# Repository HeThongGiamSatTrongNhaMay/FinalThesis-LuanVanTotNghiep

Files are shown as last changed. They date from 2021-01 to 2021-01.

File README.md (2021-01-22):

Monitoring System in Factory Using LoRaWAN Technology - Hệ Thống Giám Sát Thiết Bị Trong Nhà Máy
==============================
This repository contains a proof-of-concept implementation of a Monitoring 
System in Factory using LoRaWAN technology. It includes a single channel 
LoRaWAN gateway(from ESP8266, and SX1278 tranceiver) and 4 LoRaWAN node
(from ATmega328P and DHT11, DHT22 sensor, PZEM004T).

The code is for testing and development purposes only, and is not meant 
for production usage. 

Engine for gateway is based on code base of Single Channel gateway for RaspberryPI
which is developed by Thomas Telkamp. Code was ported and extended to run
on ESP 8266 mcu and provide RTC, Webserver and DNS services.

Topology for this project : 4 nodes (2 measure humidity and temperature; 2 measure ac energy).
A LoRaWAN gateway pushes data from these 4 nodes to network server TTN. Data then is forwarded 
to IoT Cloud ThingSpeak. Source code, lib and hardware are saved in this repository.

Maintained by Minh Chau (huynhminhchau.k14@gmail.com)

Features
--------
- listen on configurable frequency and spreading factor
- SF7 to SF12
- status updates
- can forward to one server
- DNS support for server lookup
- NTP Support for time sync with internet time servers
- Webserver support (default port 8080)
- ABP Activate
- frequence 433 MHz : 410 - 525 MHz

Not (yet) supported:
- PACKET_PUSH_ACK processing
- SF7BW250 modulation
- FSK modulation
- downstream messages (tx)

Dependencies
------------

- [gBase64][1] library by Adam Rudd is now integrated in the project, no need to install
- [Time][2] library Arduino [documentation][3]
- [lmic lib][4]

Connections
-----------
In Altium Designer of this repository

Configuration
-------------

Defaults: gateway, node

- LoRa:   SF7 at 486.3 Mhz
- Server: router.cn.thethings.network, port 1700  (The Things Network: router.cn.thethings.network)

Edit .h file (ESP-sc-gway.h) to change configuration (look for: "Configure these values!").

Please set location, email and description.

License
-------
The source files in this repository are made available under the Arduino IDE
v1.8.13, except for the base64 implementation, that has been
copied from the Semtech Packet Forwader.

[1]: https://github.com/adamvr/arduino-base64
[2]: https://github.com/PaulStoffregen/Time
[3]: http://playground.arduino.cc/code/time
[4]: https://github.com/HeThongGiamSatTrongNhaMay/LuanVanTotNghiep/tree/main/lib

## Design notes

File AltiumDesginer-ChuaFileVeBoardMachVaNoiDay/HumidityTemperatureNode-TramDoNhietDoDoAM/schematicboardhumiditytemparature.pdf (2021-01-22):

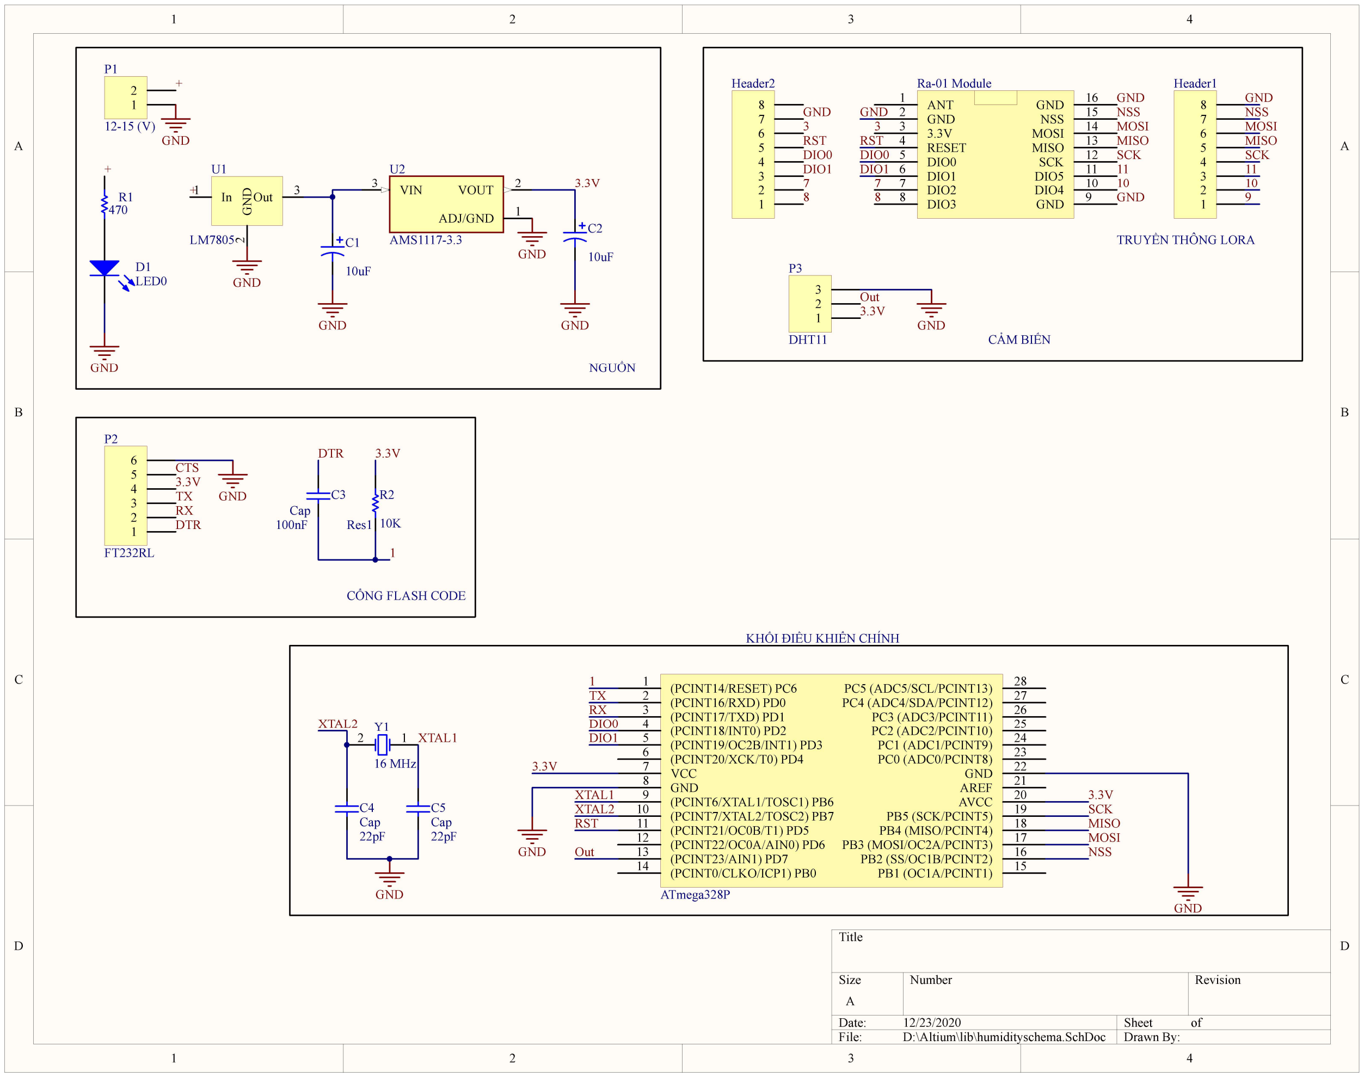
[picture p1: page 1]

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
Title

Size | Number | | Revision
A
Date: | 12/23/2020 | Sheet | of
File: | D:\Altium\lib\humidityschema.SchDoc | Drawn By:

DIO3 8

DIO2 7

DIO1 6

DIO0 5

RESET 4

3.3V 3

GND 2

ANT 1

GND | 9
DIO4 | 10 DIO5 | 11 SCK | 12 MISO | 13 MOSI | 14 NSS | 15 GND | 16

Ra-01 Module

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
Header1

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
Header2

GND
3
RST
DIO0
DIO1
7
8

GND
NSS
MOSI
MISO
SCK
11
10
9

GND
NSS
MOSI
MISO
SCK
11
10
GND

GND
3
RST
DIO0
DIO1
7
8

1

2

P1

12-15 (V)

D1
LED0

470

R1 | Out | 3 GND

2

In 1

U1

LM7805

+

+
VIN 3 | VOUT | 2
| ADJ/GND | 1

U2

AMS1117-3.3

+

10uF

C2

10uF

C1

GND

GND

GND

GND

GND

GND

3.3V

1

2

3

4

5

6

P2

FT232RL

CTS
3.3V
TX
RX
DTR

1

2

3

P3

DHT11

3.3V

Out

GND

GND

10K

R2

100nF Res1

C3
Cap

DTR 3.3V

1

(PCINT14/RESET) PC6 1
(PCINT16/RXD) PD0 2
(PCINT17/TXD) PD1 3
(PCINT18/INT0) PD2 4
(PCINT19/OC2B/INT1) PD3 5
(PCINT20/XCK/T0) PD4 6
VCC 7
GND 8
(PCINT6/XTAL1/TOSC1) PB6 9 (PCINT7/XTAL2/TOSC2) PB7 10 (PCINT21/OC0B/T1) PD5 11
(PCINT22/OC0A/AIN0) PD6 12 (PCINT23/AIN1) PD7 13
(PCINT0/CLKO/ICP1) PB0 14 | PB1 (OC1A/PCINT1) | 15 PB2 (SS/OC1B/PCINT2) | 16 PB3 (MOSI/OC2A/PCINT3) | 17 PB4 (MISO/PCINT4) | 18 PB5 (SCK/PCINT5) | 19 AVCC | 20 AREF | 21 GND | 22 PC0 (ADC0/PCINT8) | 23 PC1 (ADC1/PCINT9) | 24 PC2 (ADC2/PCINT10) | 25 PC3 (ADC3/PCINT11) | 26 PC4 (ADC4/SDA/PCINT12) | 27 PC5 (ADC5/SCL/PCINT13) | 28

ATmega328P

NGUỒN

TRUYỀN THÔNG LORA

CẢM BIẾN

CỔNG FLASH CODE

GND

GND

3.3V

3.3V

1

2 1

Y1

### 16 MHz

22pF

C5
Cap
22pF

C4
Cap

GND

XTAL1

XTAL2

TX
RX

XTAL1
XTAL2

DIO0
DIO1

RST

Out

SCK
MISO
MOSI
NSS

KHỐI ĐIỀU KHIỂN CHÍNH

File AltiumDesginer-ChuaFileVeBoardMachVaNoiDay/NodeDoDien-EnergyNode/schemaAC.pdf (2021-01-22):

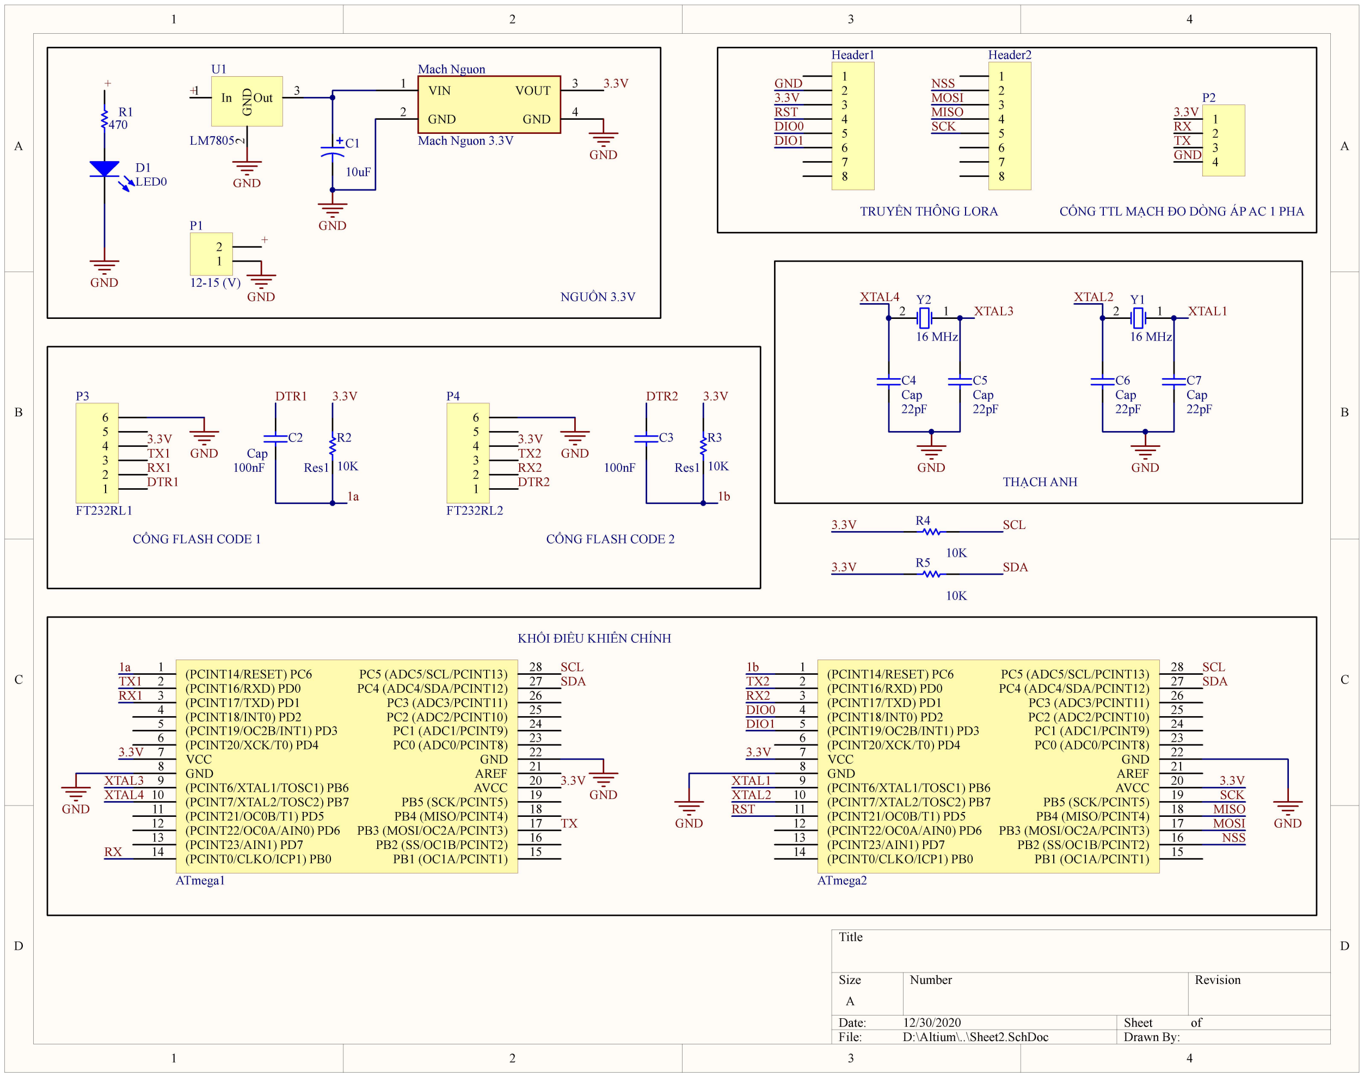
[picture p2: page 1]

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
Title

Size | Number | | Revision
A
Date: | 12/30/2020 | Sheet | of
File: | D:\Altium\..\Sheet2.SchDoc | Drawn By:

1

2

P1

12-15 (V)

D1
LED0

470

R1

Out 3 GND

2

In 1

U1

LM7805

+
+

10uF

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
FT232RL1

3.3V
TX1
RX1
DTR1

GND
10K

R2

100nF Res1

C2
Cap

DTR1 3.3V

1a

(PCINT14/RESET) PC6 1
(PCINT16/RXD) PD0 2
(PCINT17/TXD) PD1 3
(PCINT18/INT0) PD2 4
(PCINT19/OC2B/INT1) PD3 5
(PCINT20/XCK/T0) PD4 6
VCC 7
GND 8
(PCINT6/XTAL1/TOSC1) PB6 9 (PCINT7/XTAL2/TOSC2) PB7 10 (PCINT21/OC0B/T1) PD5 11
(PCINT22/OC0A/AIN0) PD6 12 (PCINT23/AIN1) PD7 13
(PCINT0/CLKO/ICP1) PB0 14 | PB1 (OC1A/PCINT1) | 15 PB2 (SS/OC1B/PCINT2) | 16 PB3 (MOSI/OC2A/PCINT3) | 17 PB4 (MISO/PCINT4) | 18 PB5 (SCK/PCINT5) | 19 AVCC | 20 AREF | 21 GND | 22 PC0 (ADC0/PCINT8) | 23 PC1 (ADC1/PCINT9) | 24 PC2 (ADC2/PCINT10) | 25 PC3 (ADC3/PCINT11) | 26 PC4 (ADC4/SDA/PCINT12) | 27 PC5 (ADC5/SCL/PCINT13) | 28

ATmega2

NGUỒN 3.3V

TRUYỀN THÔNG LORA | CỔNG TTL MẠCH ĐO DÒNG ÁP AC 1 PHA

CỔNG FLASH CODE 1

GND | GND

3.3V

3.3V

1b

2 1

Y1

### 16 MHz

22pF

C7
Cap
22pF

C6
Cap

GND

XTAL1

XTAL2

TX2
RX2

XTAL1
XTAL2

DIO0
DIO1

RST

SCK
MISO
MOSI
NSS

KHỐI ĐIỀU KHIỂN CHÍNH

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
Header2
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
Header1

GND

RST
DIO0
DIO1

NSS
MOSI
MISO
SCK

+

3.3V VIN 1

GND 2

VOUT | 3
GND | 4

Mach Nguon

Mach Nguon 3.3V
GND

3.3V

1
2
3
4

P2

2 1

Y2

### 16 MHz

22pF

C5
Cap
22pF

C4
Cap

GND

XTAL3

XTAL4

(PCINT14/RESET) PC6 1
(PCINT16/RXD) PD0 2
(PCINT17/TXD) PD1 3
(PCINT18/INT0) PD2 4
(PCINT19/OC2B/INT1) PD3 5
(PCINT20/XCK/T0) PD4 6
VCC 7
GND 8
(PCINT6/XTAL1/TOSC1) PB6 9 (PCINT7/XTAL2/TOSC2) PB7 10 (PCINT21/OC0B/T1) PD5 11
(PCINT22/OC0A/AIN0) PD6 12 (PCINT23/AIN1) PD7 13
(PCINT0/CLKO/ICP1) PB0 14 | PB1 (OC1A/PCINT1) | 15 PB2 (SS/OC1B/PCINT2) | 16 PB3 (MOSI/OC2A/PCINT3) | 17 PB4 (MISO/PCINT4) | 18 PB5 (SCK/PCINT5) | 19 AVCC | 20 AREF | 21 GND | 22 PC0 (ADC0/PCINT8) | 23 PC1 (ADC1/PCINT9) | 24 PC2 (ADC2/PCINT10) | 25 PC3 (ADC3/PCINT11) | 26 PC4 (ADC4/SDA/PCINT12) | 27 PC5 (ADC5/SCL/PCINT13) | 28

ATmega1

1

2

3

4

5

6

P4

FT232RL2

3.3V
TX2
RX2
DTR2

GND
10K

R3

100nF Res1

C3

DTR2 3.3V

1b

CỔNG FLASH CODE 2

SCL
SDA

SCL
SDA

3.3V
GND

3.3V

GND

1a
TX1
RX1

XTAL3
XTAL4

3.3V
RX
TX
GND

TX

RX

THẠCH ANH

10K

R4 3.3V | SCL

10K

R5 3.3V | SDA

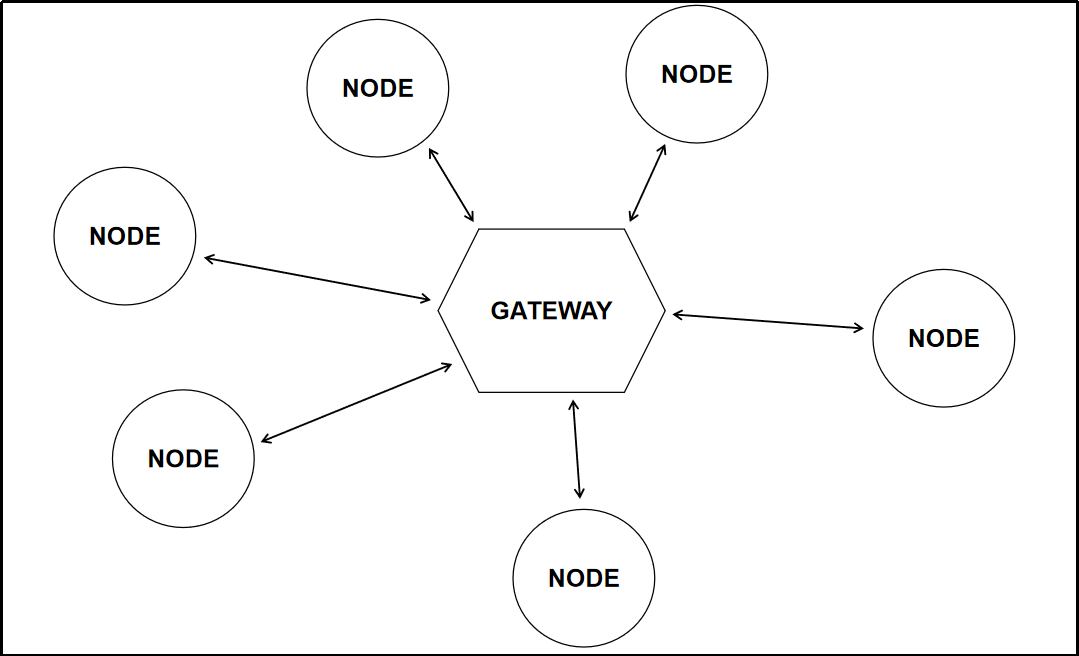
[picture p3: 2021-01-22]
topology.png

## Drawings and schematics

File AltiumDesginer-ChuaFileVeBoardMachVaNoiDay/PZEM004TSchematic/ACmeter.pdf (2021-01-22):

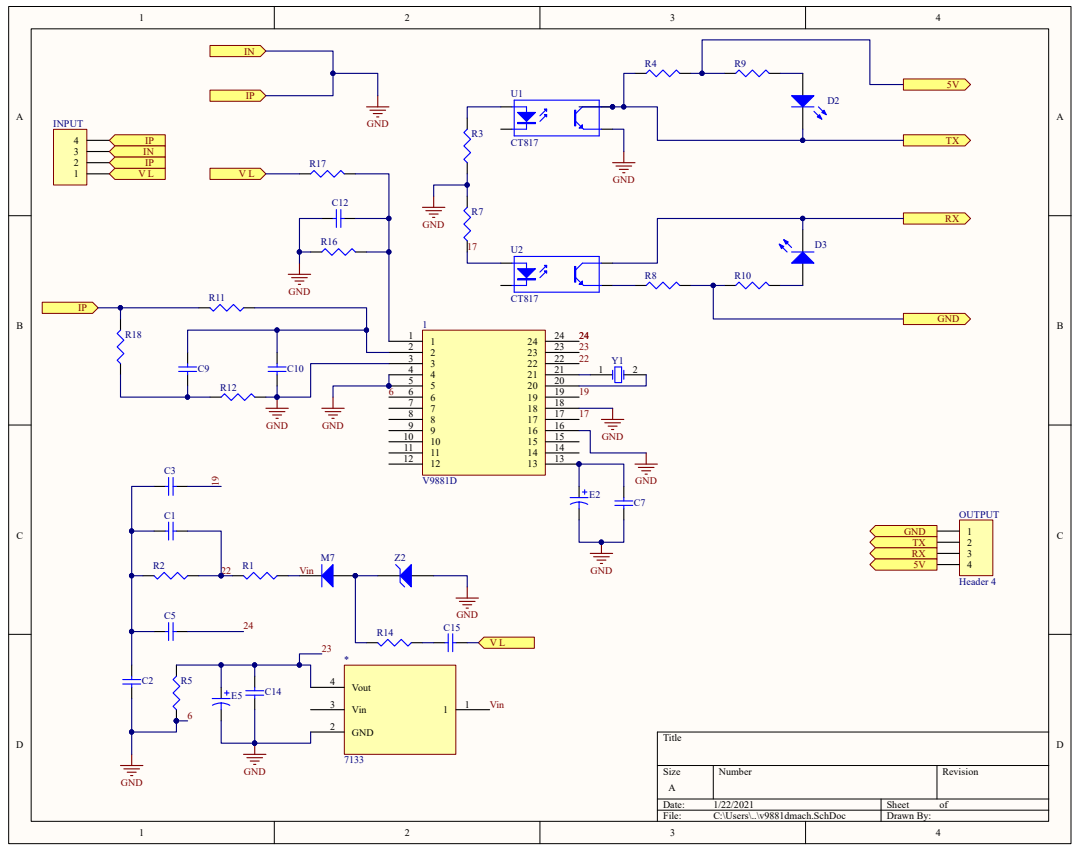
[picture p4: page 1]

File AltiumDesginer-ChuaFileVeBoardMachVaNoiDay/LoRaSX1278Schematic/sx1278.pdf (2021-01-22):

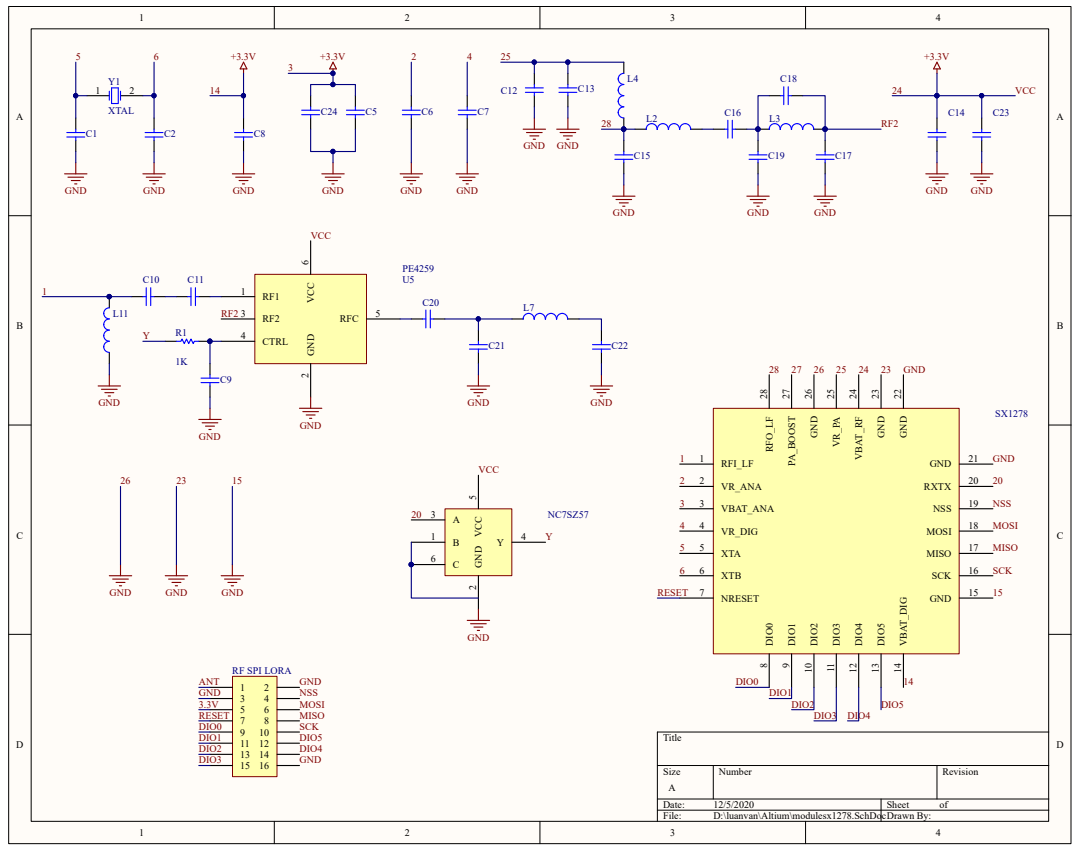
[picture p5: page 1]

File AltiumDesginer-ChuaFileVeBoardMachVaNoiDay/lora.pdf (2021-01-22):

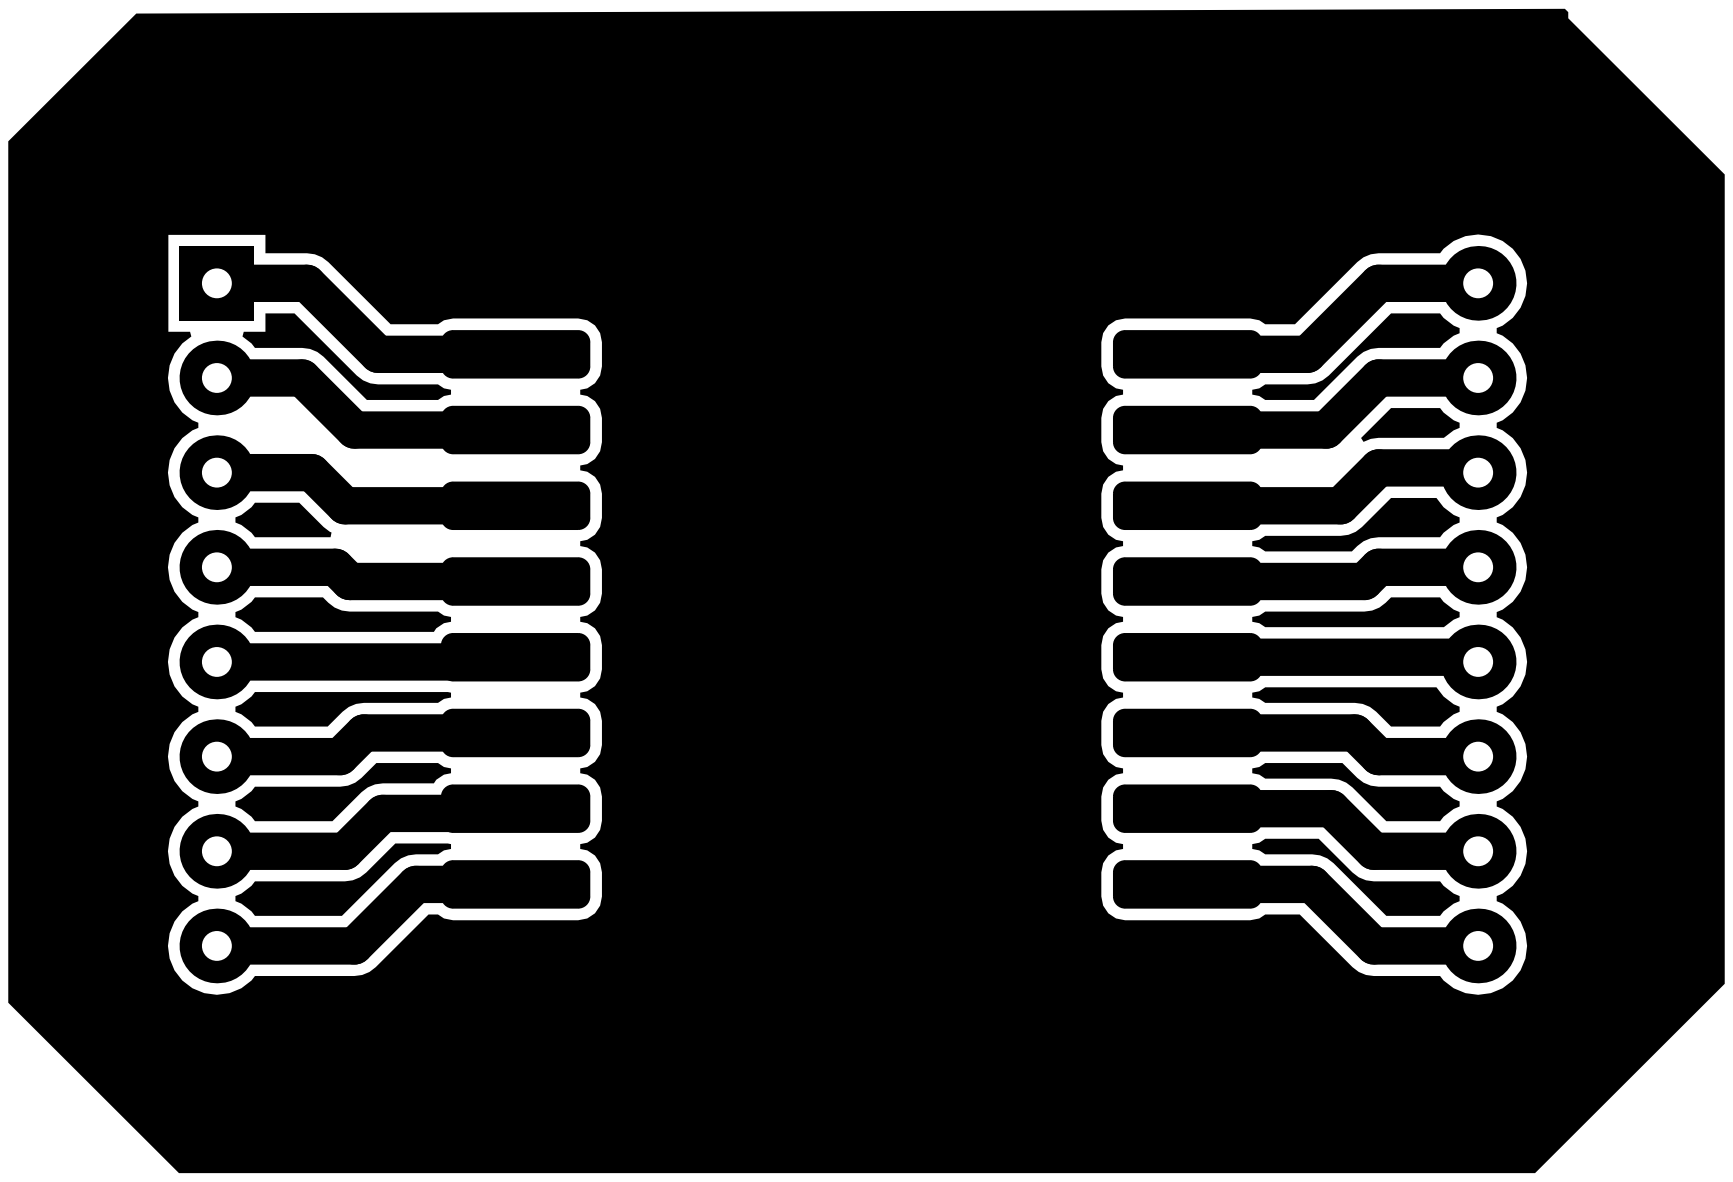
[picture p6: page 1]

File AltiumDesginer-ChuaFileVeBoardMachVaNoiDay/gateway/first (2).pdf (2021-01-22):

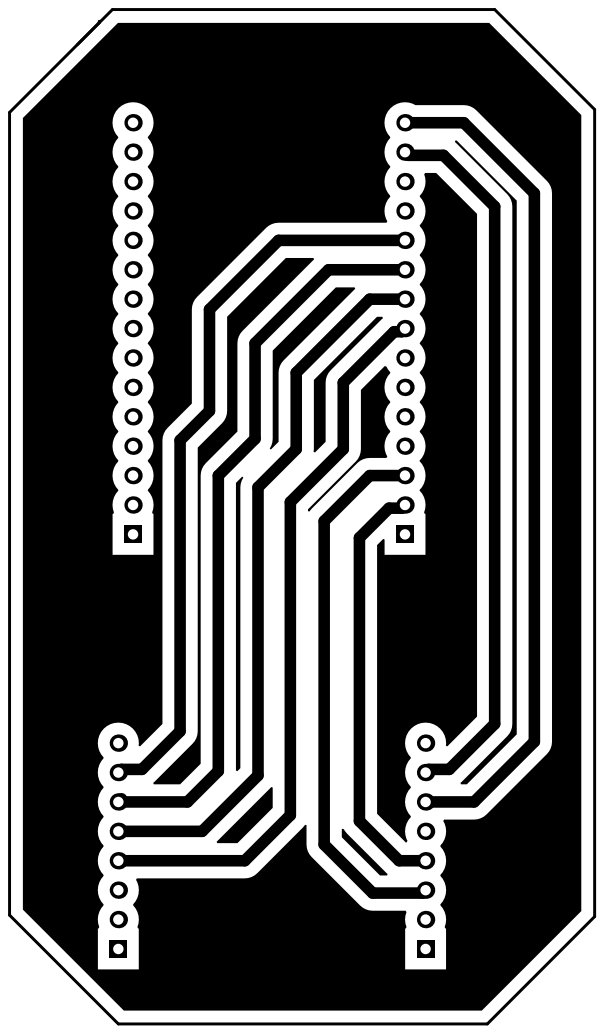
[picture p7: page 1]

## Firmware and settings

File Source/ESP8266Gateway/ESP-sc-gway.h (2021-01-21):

//
// Author: Maarten Westenberg
// Version: 1.0.0
// Date: 2016-03-25
//
// This file contains a number of compile-time settings that can be set on (=1) or off (=0)
// The disadvantage of compile time is minor compared to the memory gain of not having
// too much code compiled and loaded on your ESP8266.
//
// See http://pubsubclient.knolleary.net/api.html for API description of MQTT
//
//
// 2016-06-12 - Charles-Henri Hallard (http://hallard.me and http://github.com/hallard)
//              added support for WeMos Lora Gateway
//              added AP mode (for OTA)
//              added Over The Air (OTA) feature
//              added support for onboard WS2812 RGB Led
//              refactored include source file
//              see https://github.com/hallard/WeMos-Lora
//
// ----------------------------------------------------------------------------------------

#include <Arduino.h>

#define VERSION " ! V. 1.1.3, 110616"

// Enable WeMos Lora Shield Gateway
// see https://github.com/hallard/WeMos-Lora
// Uncomment this line if you're using this shield as gateway


/*******************************************************************************

   Configure these values if necessary!

 *******************************************************************************/

// WiFi definitions
// Setup your Wifi SSID and password
// If your device already connected to your Wifi, then
// let as is (stars), it will connect using
// your previous saved SDK credentials

//#define STASSID    "Pelab_2.4G"
//#define STAPSK    "Pelab12345678910"

//#define STASSID    "Ngoc Hien 1"
//#define STAPSK    "aaaabbbb"

#define STASSID    "iPhone"
#define STAPSK    "123456789"

// MQTT definitions
#define _TTN_SERVER "router.cn.thethings.network"


// TTN related
#define SERVER1 _TTN_SERVER    // The Things Network: croft.thethings.girovito.nl "54.72.145.119"
#define _TTN_PORT 1700            // The port on which to send data


// Gateway Ident definitions
#define _DESCRIPTION "ESP Gateway"

// SX1276 - ESP8266 connections
#define DEFAULT_PIN_SS    15          // GPIO15, D8
#define DEFAULT_PIN_DIO0  5           // GPIO5,  D1
#define DEFAULT_PIN_RST   NOT_A_PIN   // Unused


#define STATISTICS 1    // Gather statistics on sensor and Wifi status
#define DEBUG 1         // Initial value of debug var. Can be changed using the admin webserver
// For operational use, set initial DEBUG vaulue 0


#define A_MAXBUFSIZE 192  // Must be larger than 128, but small enough to work
#define _BAUDRATE 115200  // Works for debug messages to serial momitor (if attached).

// ntp
#define NTP_TIMESERVER "ch.pool.ntp.org"  // Country and region specific
#define NTP_INTERVAL  3600  // How often doe we want time NTP synchronization
#define NTP_TIMEZONES 7     // How far is our Timezone from UTC (excl daylight saving/summer time)

// ============================================================================
// Set all definitions for Gateway
// ============================================================================

#define REG_FIFO                    0x00
#define REG_FIFO_ADDR_PTR           0x0D
#define REG_FIFO_TX_BASE_AD         0x0E
#define REG_FIFO_RX_BASE_AD         0x0F
#define REG_RX_NB_BYTES             0x13
#define REG_OPMODE                  0x01
#define REG_FIFO_RX_CURRENT_ADDR    0x10
#define REG_IRQ_FLAGS               0x12
#define REG_DIO_MAPPING_1           0x40
#define REG_DIO_MAPPING_2           0x41
#define REG_MODEM_CONFIG            0x1D
#define REG_MODEM_CONFIG2           0x1E
#define REG_MODEM_CONFIG3           0x26
#define REG_SYMB_TIMEOUT_LSB        0x1F
#define REG_PKT_SNR_VALUE           0x19
#define REG_PAYLOAD_LENGTH          0x22
#define REG_IRQ_FLAGS_MASK          0x11
#define REG_MAX_PAYLOAD_LENGTH      0x23
#define REG_HOP_PERIOD              0x24
#define REG_SYNC_WORD               0x39
#define REG_VERSION                 0x42

#define SX72_MODE_RX_CONTINUOS      0x85
#define SX72_MODE_TX                0x83
#define SX72_MODE_SLEEP             0x80
#define SX72_MODE_STANDBY           0x81

#define PAYLOAD_LENGTH              0x40

// LOW NOISE AMPLIFIER
#define REG_LNA                     0x0C
#define LNA_MAX_GAIN                0x23
#define LNA_OFF_GAIN                0x00
#define LNA_LOW_GAIN                0x20

// CONF REG
#define REG1                        0x0A
#define REG2                        0x84

#define SX72_MC2_FSK                0x00
#define SX72_MC2_SF7                0x70
#define SX72_MC2_SF8                0x80
#define SX72_MC2_SF9                0x90
#define SX72_MC2_SF10               0xA0
#define SX72_MC2_SF11               0xB0
#define SX72_MC2_SF12               0xC0

#define SX72_MC1_LOW_DATA_RATE_OPTIMIZE  0x01   // mandated for SF11 and SF12

// FRF
#define REG_FRF_MSB       0x06
#define REG_FRF_MID       0x07
#define REG_FRF_LSB       0x08


#define FRF_MSB           0xD9    // 868.1 Mhz
#define FRF_MID           0x06
#define FRF_LSB           0x66
#define BUFLEN 2048               //Max length of buffer

#define PROTOCOL_VERSION  1
#define PKT_PUSH_DATA     0
#define PKT_PUSH_ACK      1
#define PKT_PULL_DATA     2
#define PKT_PULL_RESP     3
#define PKT_PULL_ACK      4

#define TX_BUFF_SIZE  2048
#define STATUS_SIZE   512           // This should(!) be enough based on the static text part.. was 1024

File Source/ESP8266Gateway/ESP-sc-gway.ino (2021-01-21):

#include <sys/time.h>
#include <SPI.h>
#include <ESP8266WiFi.h>
#include <TimeLib.h>	// https://github.com/PaulStoffregen/Time)
#include <WiFiUdp.h> 

extern "C" {
#include "user_interface.h"
#include "lwip/err.h"
#include "lwip/dns.h"
}

#include "gBase64.h"			// https://github.com/adamvr/arduino-base64 (I changed the name)
#include "ESP-sc-gway.h"	// This file contains configuration of GWay

int debug = 1;									// Debug level! 0 is no msgs, 1 normal, 2 is extensive

using namespace std;

char message[256];
char b64[256];
bool sx1272 = true;								// Actually we use sx1276/RFM95
byte receivedbytes;

uint32_t cp_nb_rx_rcv;
uint32_t cp_nb_rx_ok;
uint32_t cp_nb_rx_bad;
uint32_t cp_nb_rx_nocrc;
uint32_t cp_up_pkt_fwd;

enum sf_t { SF7 = 7, SF8, SF9, SF10, SF11, SF12 };

uint8_t MAC_array[6];
char MAC_char[18] = {0};


/*******************************************************************************

   Configure these values if necessary!

 *******************************************************************************/

// SX1276 - ESP8266 connections
int ssPin = DEFAULT_PIN_SS;
int dio0  = DEFAULT_PIN_DIO0;
int RST   = DEFAULT_PIN_RST;

// Set spreading factor (SF7 - SF12)
sf_t sf = SF7;

// Set center frequency. If in doubt, choose the first one, comment all others
// Each "real" gateway should support the first 3 frequencies according to LoRa spec.
uint32_t  freq = 486300000; 					// Channel 0, 486.3 MHz
//uint32_t  freq = 486500000; 					// Channel 1, 486.5 MHz
//uint32_t  freq = 486700000; 					// in Mhz! (486.7)
//uint32_t  freq = 486900000; 					// in Mhz! (486.9)
//uint32_t  freq = 487100000; 					// in Mhz! (487.1)
//uint32_t  freq = 487300000; 					// in Mhz! (487.3)
//uint32_t  freq = 487500000; 					// in Mhz! (487.5)
//uint32_t  freq = 487700000; 					// in Mhz! (487.7)

IPAddress ttnServer;							// IP Address of thethingsnetwork server

WiFiUDP Udp;
uint32_t lasttime;


// ----------------------------------------------------------------------------
// DIE is not use actively in the source code anymore.
// It is replaced by a Serial.print command so we know that we have a problem
// somewhere.
// There are at least 3 other ways to restart the ESP. Pick one if you want.
// ----------------------------------------------------------------------------
void die(const char *s)
{
  Serial.println(s);
  delay(50);
  // system_restart();						// SDK function
  // ESP.reset();
  abort();									// Within a second
}


// ----------------------------------------------------------------------------
// Convert a float to string for printing
// f is value to convert
// p is precision in decimal digits
// val is character array for results
// ----------------------------------------------------------------------------
void ftoa(float f, char *val, int p) {
  int j = 1;
  int ival, fval;
  char b[6];

  for (int i = 0; i < p; i++) {
    j = j * 10;
  }

  ival = (int) f;								// Make integer part
  fval = (int) ((f - ival) * j);					// Make fraction. Has same sign as integer part
  if (fval < 0) fval = -fval;					// So if it is negative make fraction positive again.
  // sprintf does NOT fit in memory
  strcat(val, itoa(ival, b, 10));
  strcat(val, ".");							// decimal point

  itoa(fval, b, 10);
  for (int i = 0; i < (p - strlen(b)); i++) strcat(val, "0");
  // Fraction can be anything from 0 to 10^p , so can have less digits
  strcat(val, b);
}


// ----------------------------------------------------------------------------
// GET THE DNS SERVER IP address
// ----------------------------------------------------------------------------
IPAddress getDnsIP() {
  const ip_addr_t* dns_ip = dns_getserver(0);
  IPAddress dns = IPAddress(dns_ip->addr);
  return ((IPAddress) dns);
}


// ----------------------------------------------------------------------------
// Read a package
//
// ----------------------------------------------------------------------------
void readUdp(int packetSize)
{
  uint8_t receiveBuffer[64]; //buffer to hold incoming packet
  Udp.read(receiveBuffer, packetSize);
  receiveBuffer[packetSize] = 0;
  IPAddress remoteIpNo = Udp.remoteIP();
  unsigned int remotePortNo = Udp.remotePort();
  if (debug >= 1) {
    Serial.print(F(" Received packet of size "));
    Serial.print(packetSize);
    Serial.print(F(" From "));
    Serial.print(remoteIpNo);
    Serial.print(F(", port "));
    Serial.print(remotePortNo);
    Serial.print(F(", Contents: 0x"));
    for (int i = 0; i < packetSize; i++) {
      Serial.printf("%02X:", receiveBuffer[i]);
    }
    Serial.println();
  }
}



// ----------------------------------------------------------------------------
// Send an UDP/DGRAM message to the MQTT server
// If we send to more than one host (not sure why) then we need to set sockaddr
// before sending.
// ----------------------------------------------------------------------------
void sendUdp(char *msg, int length) {
  int l;
  bool err = true ;
  //send the update
  Udp.beginPacket(ttnServer, (int) _TTN_PORT);

  if ((l = Udp.write((char *)msg, length)) != length) {
    Serial.println(F("sendUdp:: Error write"));
  } else {
    err = false;
    
    Serial.printf("sendUdp: sent %d bytes", l);
   
  }

  yield();
  Udp.endPacket();
}





// =================================================================================
// LORA GATEWAY FUNCTIONS
// The LoRa supporting functions are in the section below

// ----------------------------------------------------------------------------
// The SS (Chip select) pin is used to make sure the RFM95 is selected
// ----------------------------------------------------------------------------
inline void selectreceiver()
{
  digitalWrite(ssPin, LOW);
}

// ----------------------------------------------------------------------------
// ... or unselected
// ----------------------------------------------------------------------------
inline void unselectreceiver()
{
  digitalWrite(ssPin, HIGH);
}

// ----------------------------------------------------------------------------
// Read one byte value, par addr is address
// Returns the value of register(addr)
// ----------------------------------------------------------------------------
byte readRegister(byte addr)
{
  selectreceiver();
  SPI.beginTransaction(SPISettings(50000, MSBFIRST, SPI_MODE0));
  SPI.transfer(addr & 0x7F);
  uint8_t res = SPI.transfer(0x00);
  SPI.endTransaction();
  unselectreceiver();
  return res;
}

// ----------------------------------------------------------------------------
// Write value to a register with address addr.
// Function writes one byte at a time.
// ----------------------------------------------------------------------------
void writeRegister(byte addr, byte value)
{
  unsigned char spibuf[2];

  spibuf[0] = addr | 0x80;
  spibuf[1] = value;
  selectreceiver();
  SPI.beginTransaction(SPISettings(50000, MSBFIRST, SPI_MODE0));
  SPI.transfer(spibuf[0]);
  SPI.transfer(spibuf[1]);
  SPI.endTransaction();
  unselectreceiver();
}

// ----------------------------------------------------------------------------
// This LoRa function reads a message from the LoRa transceiver
// returns true when message correctly received or fails on error
// (CRC error for example)
// ----------------------------------------------------------------------------
bool receivePkt(char *payload)
{
  // clear rxDone
  writeRegister(REG_IRQ_FLAGS, 0x40);

  int irqflags = readRegister(REG_IRQ_FLAGS);

  cp_nb_rx_rcv++;											// Receive statistics counter

  //  payload crc: 0x20
  if ((irqflags & 0x20) == 0x20)
  {
    Serial.println(F("CRC error"));
    writeRegister(REG_IRQ_FLAGS, 0x20);
    return false;
  } else {

    cp_nb_rx_ok++;										// Receive OK statistics counter

    byte currentAddr = readRegister(REG_FIFO_RX_CURRENT_ADDR);
    byte receivedCount = readRegister(REG_RX_NB_BYTES);
    receivedbytes = receivedCount;

    writeRegister(REG_FIFO_ADDR_PTR, currentAddr);

    for (int i = 0; i < receivedCount; i++)
    {
      payload[i] = (char)readRegister(REG_FIFO);
    }
  }
  return true;
}

// ----------------------------------------------------------------------------
// Setup the LoRa environment on the connected transceiver.
// - Determine the correct transceiver type (sx1272/RFM92 or sx1276/RFM95)
// - Set the frequency to listen to (1-channel remember)
// - Set Spreading Factor (standard SF7)
// The reset RST pin might not be necessary for at least the RGM95 transceiver
// ----------------------------------------------------------------------------
void SetupLoRa()
{
  Serial.println(F("Trying to Setup LoRa Module with"));
  Serial.printf("CS=GPIO%d  DIO0=GPIO%d  Reset=", ssPin, dio0 );

  if (RST == NOT_A_PIN ) {
    Serial.println(F("Unused"));
  } else {
    Serial.printf("GPIO%d\r\n", RST);
    digitalWrite(RST, HIGH);
    delay(100);
    digitalWrite(RST, LOW);
    delay(100);
  }

  byte version = readRegister(REG_VERSION);					// Read the LoRa chip version id
  if (version == 0x22) {
    // sx1272
    Serial.println(F("SX1272 detected, starting."));
    sx1272 = true;
  } else {
    // sx1276?
    if (RST != NOT_A_PIN ) {
      digitalWrite(RST, LOW);
      delay(100);
      digitalWrite(RST, HIGH);
      delay(100);
    }

    version = readRegister(REG_VERSION);
    if (version == 0x12) {
      // sx1276
      Serial.println(F("SX1276 detected, starting."));
      sx1272 = false;
    } else {
      Serial.print(F("Unrecognized transceiver, version: 0x"));
      Serial.printf("%02X", version);
      die("");
    }
  }

  writeRegister(REG_OPMODE, SX72_MODE_SLEEP);

  // set frequency
  uint64_t frf = ((uint64_t)freq << 19) / 32000000;
  writeRegister(REG_FRF_MSB, (uint8_t)(frf >> 16) );
  writeRegister(REG_FRF_MID, (uint8_t)(frf >> 8) );
  writeRegister(REG_FRF_LSB, (uint8_t)(frf >> 0) );

  writeRegister(REG_SYNC_WORD, 0x34); // LoRaWAN public sync word

  // Set spreading Factor
  if (sx1272) {
    if (sf == SF11 || sf == SF12) {
      writeRegister(REG_MODEM_CONFIG, 0x0B);
    } else {
      writeRegister(REG_MODEM_CONFIG, 0x0A);
    }
    writeRegister(REG_MODEM_CONFIG2, (sf << 4) | 0x04);
  } else {
    if (sf == SF11 || sf == SF12) {
      writeRegister(REG_MODEM_CONFIG3, 0x0C);
    } else {
      writeRegister(REG_MODEM_CONFIG3, 0x04);
    }
    writeRegister(REG_MODEM_CONFIG, 0x72);
    writeRegister(REG_MODEM_CONFIG2, (sf << 4) | 0x04);
  }

  if (sf == SF10 || sf == SF11 || sf == SF12) {
    writeRegister(REG_SYMB_TIMEOUT_LSB, 0x05);
  } else {
    writeRegister(REG_SYMB_TIMEOUT_LSB, 0x08);
  }
  writeRegister(REG_MAX_PAYLOAD_LENGTH, 0x80);
  writeRegister(REG_PAYLOAD_LENGTH, PAYLOAD_LENGTH);
  writeRegister(REG_HOP_PERIOD, 0xFF);
  writeRegister(REG_FIFO_ADDR_PTR, readRegister(REG_FIFO_RX_BASE_AD));

  // Set Continous Receive Mode
  writeRegister(REG_LNA, LNA_MAX_GAIN);  // max lna gain
  writeRegister(REG_OPMODE, SX72_MODE_RX_CONTINUOS);
}


// ----------------------------------------------------------------------------
// Send periodic status message to server even when we do not receive any
// data.
// Parameter is socketr to TX to
// ----------------------------------------------------------------------------


// ----------------------------------------------------------------------------
// Receive a LoRa package
//
// Receive a LoRa message and fill the buff_up char buffer.
// returns values:
// - returns the length of string returned in buff_up
// - returns -1 when no message arrived.
// ----------------------------------------------------------------------------
int receivepacket(char *buff_up) {

  long int SNR;
  int rssicorr;
  char cfreq[12] = {0};			  // Character array to hold freq in MHz
  if (digitalRead(dio0) == 1)	// READY?
  { 
    if (receivePkt(message)) {
      byte value = readRegister(REG_PKT_SNR_VALUE);

      if ( value & 0x80 ) { // The SNR sign bit is 1
        // Invert and divide by 4
        value = ( ( ~value + 1 ) & 0xFF ) >> 2;
        SNR = -value;
      } else {
        // Divide by 4
        SNR = ( value & 0xFF ) >> 2;
      }

      if (sx1272) {
        rssicorr = 139;
      } else {											// Probably SX1276 or RFM95
        rssicorr = 157;
      }

      Serial.print(F("Packet RSSI: "));
      Serial.print(readRegister(0x1A) - rssicorr);
      Serial.print(F(" RSSI: "));
      Serial.print(readRegister(0x1B) - rssicorr);
      Serial.print(F(" SNR: "));
      Serial.print(SNR);
      Serial.print(F(" Length: "));
      Serial.print((int)receivedbytes);
      Serial.println();
      yield();
      

      int j;

      // XXX Base64 library is nopad. So we may have to add padding characters until
      // 	length is multiple of 4!
      int encodedLen = base64_enc_len(receivedbytes);		// max 341
      base64_encode(b64, message, receivedbytes);			// max 341

      //j = bin_to_b64((uint8_t *)message, receivedbytes, (char *)(b64), 341);
      //fwrite(b64, sizeof(char), j, stdout);

      int buff_index = 0;

      // pre-fill the data buffer with fixed fields
      buff_up[0] = PROTOCOL_VERSION;
      buff_up[3] = PKT_PUSH_DATA;

      // XXX READ MAC ADDRESS OF ESP8266
      buff_up[4]  = MAC_array[0];
      buff_up[5]  = MAC_array[1];
      buff_up[6]  = MAC_array[2];
      buff_up[7]  = 0x05;
      buff_up[8]  = 0x05;
      buff_up[9]  = MAC_array[3];
      buff_up[10] = MAC_array[4];
      buff_up[11] = MAC_array[5];

      // start composing datagram with the header
      uint8_t token_h = (uint8_t)rand(); 					// random token
      uint8_t token_l = (uint8_t)rand(); 					// random token
      buff_up[1] = token_h;
      buff_up[2] = token_l;
      buff_index = 12; /* 12-byte header */

      // TODO: tmst can jump if time is (re)set, not good.
      struct timeval now;
      gettimeofday(&now, NULL);
      uint32_t tmst = (uint32_t)(now.tv_sec * 1000000 + now.tv_usec);

      // start of JSON structure that will make payload
      memcpy((void *)(buff_up + buff_index), (void *)"{\"rxpk\":[", 9);
      buff_index += 9;
      buff_up[buff_index] = '{';
      ++buff_index;
      j = snprintf((char *)(buff_up + buff_index), TX_BUFF_SIZE - buff_index, "\"tmst\":%u", tmst);
      buff_index += j;
      ftoa((double)freq / 1000000, cfreq, 6);						// XXX This can be done better
      j = snprintf((char *)(buff_up + buff_index), TX_BUFF_SIZE - buff_index, ",\"chan\":%1u,\"rfch\":%1u,\"freq\":%s", 0, 0, cfreq);
      buff_index += j;
      memcpy((void *)(buff_up + buff_index), (void *)",\"stat\":1", 9);
      buff_index += 9;
      memcpy((void *)(buff_up + buff_index), (void *)",\"modu\":\"LORA\"", 14);
      buff_index += 14;
      /* Lora datarate & bandwidth, 16-19 useful chars */
      switch (sf) {
        case SF7:
          memcpy((void *)(buff_up + buff_index), (void *)",\"datr\":\"SF7", 12);
          buff_index += 12;
          break;
        case SF8:
          memcpy((void *)(buff_up + buff_index), (void *)",\"datr\":\"SF8", 12);
          buff_index += 12;
          break;
        case SF9:
          memcpy((void *)(buff_up + buff_index), (void *)",\"datr\":\"SF9", 12);
          buff_index += 12;
          break;
        case SF10:
          memcpy((void *)(buff_up + buff_index), (void *)",\"datr\":\"SF10", 13);
          buff_index += 13;
          break;
        case SF11:
          memcpy((void *)(buff_up + buff_index), (void *)",\"datr\":\"SF11", 13);
          buff_index += 13;
          break;
        case SF12:
          memcpy((void *)(buff_up + buff_index), (void *)",\"datr\":\"SF12", 13);
          buff_index += 13;
          break;
        default:
          memcpy((void *)(buff_up + buff_index), (void *)",\"datr\":\"SF?", 12);
          buff_index += 12;
      }
      memcpy((void *)(buff_up + buff_index), (void *)"BW125\"", 6);
      buff_index += 6;
      memcpy((void *)(buff_up + buff_index), (void *)",\"codr\":\"4/5\"", 13);
      buff_index += 13;
      j = snprintf((char *)(buff_up + buff_index), TX_BUFF_SIZE - buff_index, ",\"lsnr\":%li", SNR);
      buff_index += j;
      j = snprintf((char *)(buff_up + buff_index), TX_BUFF_SIZE - buff_index, ",\"rssi\":%d,\"size\":%u", readRegister(0x1A) - rssicorr, receivedbytes);
      buff_index += j;
      memcpy((void *)(buff_up + buff_index), (void *)",\"data\":\"", 9);
      buff_index += 9;

      // Use gBase64 library
      encodedLen = base64_enc_len(receivedbytes);		// max 341
      j = base64_encode((char *)(buff_up + buff_index), message, receivedbytes);

      buff_index += j;
      buff_up[buff_index++] = '"';

      // End of packet serialization
      buff_up[buff_index++] = '}';
      buff_up[buff_index++] = ']';
      // end of JSON datagram payload */
      buff_up[buff_index++] = '}';
      buff_up[buff_index] = 0; 						// add string terminator, for safety

      
      Serial.print(F("rxpk update: "));
      Serial.println((char *)(buff_up + 12));		// DEBUG: display JSON payload
      
      return (buff_index);

    } // received a message
  } // dio0=1
  return (-1);
}



// ----------------------------------------------------------------------------
// Output the 4-byte IP address for easy printing
// ----------------------------------------------------------------------------
String printIP(IPAddress ipa) {
  String response;
  response += (String)ipa[0]; response += ".";
  response += (String)ipa[1]; response += ".";
  response += (String)ipa[2]; response += ".";
  response += (String)ipa[3];
  return (response);
}


// ========================================================================
// MAIN PROGRAM (SETUP AND LOOP)

// ----------------------------------------------------------------------------
// Setup code (one time)
// ----------------------------------------------------------------------------
void setup () {

  Serial.begin(_BAUDRATE);	// As fast as possible for bus

  // Wi-Fi Connection
  WiFi.mode(WIFI_STA);          // dang ky cho esp8266 lam mot diem truy cap wifi vao router local = access point
  WiFi.begin(STASSID, STAPSK);  // ket noi wifi nha de truy cap vao internet
  Serial.println();
  Serial.println("Connect to wifi");
  while(WiFi.status()!=WL_CONNECTED){
    Serial.print('.');  
    delay(500);
  }
  Serial.print("Connected! IP address: "); // IP cua esp8266 trong mang wifi local
  Serial.println(WiFi.localIP());
  
  Serial.print("IP server: ");    // IP cua server China The Things Network
  WiFi.hostByName(_TTN_SERVER, ttnServer);  // tra ve dia chi ip cua server cua ban China router.cn.thethings.network
                                            // minh dung router cua ban China vi minh muon dang ky tan so 470 MHz

  //UDP Connection 
  bool conectadoUDP = (Udp.begin((int)_TTN_PORT) == 1);  // establish UDP connection and listening at this port _TTN_PORT
                                                             //, ==1 de kiem tra da connect chua 
  if (conectadoUDP){
    Serial.print("Conectado ao servidor: ");   // connect to server ttnServer to listen incoming UDP packets from this port 
    Serial.println(ttnServer);            // in ra dia chi ip cua server router.cn.thethings.network, sau khi da convert o line 37
  }                                       // y la UDP se lang nghe incoming packets o port _TTN_PORT=1700
  
  char MAC_char[18] = {0};
  WiFi.macAddress(MAC_array);           // get MAC address of ESP8266 device, return 6 byte array 
  for (int i = 0; i<sizeof(MAC_array);++i){
    sprintf(MAC_char, "%s%02x:", MAC_char, MAC_array[i]);
  }
  Serial.print(F("MAC: "));
  Serial.println(MAC_char);



  // Configure IO Pin
  pinMode(ssPin, OUTPUT);
  pinMode(dio0, INPUT);
  pinMode(RST, OUTPUT);

  SPI.begin();
  delay(100);
  SetupLoRa();
  delay(100);

  
}
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
void loop ()
{
  yield();
  
  int buff_index;
  char buff_up[TX_BUFF_SIZE]; 						// buffer to compose the upstream packet

  // Receive Lora messages
  if ((buff_index = receivepacket(buff_up)) >= 0) {	// read is successful
    yield();
    sendUdp(buff_up, buff_index);					// We can send to multiple sockets if necessary
  }


  // Receive WiFi messages. This is important since the TTN broker will return confirmation
  // messages on UDP for every message sent by the gateway.
  int packetSize = Udp.parsePacket();
  if (packetSize > 0) {
    readUdp(packetSize);
  }

  uint32_t nowseconds = (uint32_t) millis() / 1000;
  if (nowseconds - lasttime >= 30) {					// Send status every 30 seconds
    enviaDados();
    lasttime = nowseconds;
  }
}

// ham gui len server
void enviaDados(){
  // message kieu json gui tu esp8266 len server TTN
  char msg[] = "000000000000"
  "{"
  "\"rxpk\":[{"
  "\"tmst\":13202941,"
  "\"chan\":0,"
  "\"rfch\":0,"
//  "\"freq\":915.299987,"
  "\"freq\":486.299987,"
  "\"stat\":1,"
  "\"modu\":\"LORA\","
  "\"datr\":\"SF7BW125\","
  "\"codr\":\"4/5\","
  "\"lsnr\":0,"
  "\"rssi\":-60,"
  "\"size\":23,"
  "\"data\":\"QJkUASYAAAABodsMSXtu+qxauVfYT/U=\""
  "}]"
  "}";

  int bytesEnviar = sizeof(msg)-1;

  msg[0] = 1; // PROTOCOL VERSION
  msg[1] = (uint8_t)rand();
  msg[2] = (uint8_t)rand();
  msg[3] = 0; // PKT_PUSH_DATA, always 0x00
  msg[4] = MAC_array[0]; // from 4-11 is gateway EUI
  msg[5] = MAC_array[1];
  msg[6] = MAC_array[2];
  msg[7] = 0x05;
  msg[8] = 0x05;
  msg[9] = MAC_array[3];
  msg[10] = MAC_array[4];
  msg[11] = MAC_array[5];

  Serial.println();
  for(int i = 0; i < 12; i++){
    Serial.printf("%02X:", msg[i]);
  }
  for(int i = 12; i < bytesEnviar ; i++){
    Serial.write(msg[i]);
  }
  Serial.println();
  sendUdp(msg, bytesEnviar);  
}

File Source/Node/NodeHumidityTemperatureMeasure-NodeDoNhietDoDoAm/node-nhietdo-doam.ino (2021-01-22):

#include <lmic.h>
#include <hal/hal.h>
#include <SPI.h>
#include <avr/wdt.h>

#include <DHT.h>
#include <DHT_U.h>

DHT dht(7, DHT11);

// LoRaWAN NwkSKey, network session key
// This is the default Semtech key, which is used by the early prototype TTN
// network.
static const PROGMEM u1_t NWKSKEY[16] = { 0xE9, 0x63, 0x8E, 0x32, 0x7D, 0x89, 0x38, 0x8B, 0x7D, 0x3C, 0x0B, 0xC0, 0xDF, 0x98, 0xCB, 0x76 };

// LoRaWAN AppSKey, application session key
// This is the default Semtech key, which is used by the early prototype TTN
// network.
static const u1_t PROGMEM APPSKEY[16] = { 0xF7, 0x1B, 0x28, 0x0B, 0xA6, 0x56, 0x5E, 0x93, 0x5D, 0x4A, 0x87, 0x1A, 0xB4, 0xB2, 0xB2, 0x75 };

// LoRaWAN end-device address (DevAddr)
static const u4_t DEVADDR = 0x26041D01; // <-- Change this address for every node!

// These callbacks are only used in over-the-air activation, so they are
// left empty here (we cannot leave them out completely unless
// DISABLE_JOIN is set in config.h, otherwise the linker will complain).
void os_getArtEui (u1_t* buf) { }
void os_getDevEui (u1_t* buf) { }
void os_getDevKey (u1_t* buf) { }

static osjob_t sendjob;

// Schedule TX every this many seconds (might become longer due to duty
// cycle limitations).
const unsigned TX_INTERVAL = 60;

// Pin mapping
const lmic_pinmap lmic_pins = {
    .nss = 10,
    .rxtx = LMIC_UNUSED_PIN,
    .rst = 5,
    .dio = {2, 3, LMIC_UNUSED_PIN},
};

void onEvent (ev_t ev) {
    Serial.print(os_getTime());
    Serial.print(": ");
    switch(ev) {
        case EV_SCAN_TIMEOUT:
            Serial.println(F("EV_SCAN_TIMEOUT"));
            break;
        case EV_BEACON_FOUND:
            Serial.println(F("EV_BEACON_FOUND"));
            break;
        case EV_BEACON_MISSED:
            Serial.println(F("EV_BEACON_MISSED"));
            break;
        case EV_BEACON_TRACKED:
            Serial.println(F("EV_BEACON_TRACKED"));
            break;
        case EV_JOINING:
            Serial.println(F("EV_JOINING"));
            break;
        case EV_JOINED:
            Serial.println(F("EV_JOINED"));
            break;
        case EV_RFU1:
            Serial.println(F("EV_RFU1"));
            break;
        case EV_JOIN_FAILED:
            Serial.println(F("EV_JOIN_FAILED"));
            break;
        case EV_REJOIN_FAILED:
            Serial.println(F("EV_REJOIN_FAILED"));
            break;
        case EV_TXCOMPLETE:
            Serial.println(F("EV_TXCOMPLETE (includes waiting for RX windows)"));
            if (LMIC.txrxFlags & TXRX_ACK)
              Serial.println(F("Received ack"));
            if (LMIC.dataLen) {
              Serial.println(F("Received "));
              Serial.println(LMIC.dataLen);
              Serial.println(F(" bytes of payload"));
            }
            // Schedule next transmission
            os_setTimedCallback(&sendjob, os_getTime()+sec2osticks(TX_INTERVAL), do_send);
            break;
        case EV_LOST_TSYNC:
            Serial.println(F("EV_LOST_TSYNC"));
            break;
        case EV_RESET:
            Serial.println(F("EV_RESET"));
            break;
        case EV_RXCOMPLETE:
            // data received in ping slot
            Serial.println(F("EV_RXCOMPLETE"));
            break;
        case EV_LINK_DEAD:
            Serial.println(F("EV_LINK_DEAD"));
            break;
        case EV_LINK_ALIVE:
            Serial.println(F("EV_LINK_ALIVE"));
            break;
         default:
            Serial.println(F("Unknown event"));
            break;
    }
}

void do_send(osjob_t* j){
    // Check if there is not a current TX/RX job running
    uint32_t humidity = dht.readHumidity(false)*100;
    uint32_t temperature = dht.readTemperature(false)*100;

    byte payload[4];
    payload[0] = highByte(humidity);
    payload[1] = lowByte(humidity);
    payload[2] = highByte(temperature);
    payload[3] = lowByte(temperature);
    
    if (LMIC.opmode & OP_TXRXPEND) {
        Serial.println(F("OP_TXRXPEND, not sending"));
    } else {
        // Prepare upstream data transmission at the next possible time.
        LMIC_setTxData2(1, payload, sizeof(payload)-1, 0);
        Serial.println(F("Packet queued"));
    }
    // Next TX is scheduled after TX_COMPLETE event.
}
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

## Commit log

2021-01-21 Source code Arduino IDE
2021-01-21 C/C++ file compile by Arduino IDE 8.1.13
2021-01-21 Compile in Arduino IDE 1.8.13
    Main source code is used in LoRaWAN gateway 1 channel, which is from ESP8266 and LoRa SX1278 module.
    This main source code was designed in Arduino IDE 1.8.13 and compile/flash to MCU ESP8266 by using Arduino IDE 1.8.13.
    I heritage the source code from Andreas Spiess and his original source code : https://github.com/marcobrianza/ESP-1ch-Gateway-v4.0/tree/LoraNode_1.3
    Because i use LoRa module SX1278 433 MHz, so his source code can't run for my device.
    I have changed his source code for my device to run.
    I also learned a lot from Mobilefish.com and his channel : https://www.youtube.com/channel/UCG5_CT_KjexxjbgNE4lVGkg
    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
2021-01-22 There are 2 file ino for 2 MCU.
    The "readvoltageandsend.ino" is used to read voltage from PZEM004T and send to the second MCU by I2C protocol.
    The "receiveandsendlora.ino" is used to receive I2C message and to send LoRaWAN package.
2021-01-22 Read energy and send to server
    The file "readvoltageandsend.ino" read AC RMS current, voltage and power factor on load.
    This 3 values are sent by I2C protocol to the second ATmega328P.
    The second MCU receives the 3 values by I2C protocol and sends to server by LoRaWAN technology.
    The "receiveandsendlora.ino" is flashed to MCU to do function above.
2021-01-22 Humidity and Temperature Node
    Trạm này đọc giá trị nhiệt độ, độ ẩm bằng cảm biến DHT11 và DHT22.
    Sau đó thì đóng gói gói tin lại và gửi đi bằng công nghệ LoRaWAN đến network server.
    This node reads temperature and humidity by using DHT11 & DHT22 sensor.
    Then packaging the message by LoRaWAN technology to send to network server TTN.
2021-01-22 Altium Desginer Lib For LoRa Module Base
    [LoRa.PcbDoc, LoRa.SchDoc, lib4lorq.PrjPCB]
2021-01-22 Schematic & PCB of Energy Node
    Trạm này đo điện nên đây là schematic và PCB để làm board cho trạm.
    This node measures energy on load, so this is schematic & PCB to implement a hardware for node.
    [PCB1.PcbDoc, PCB2.PcbDoc, PCB_Project2.PrjPCB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]
2021-01-22 Arduino, PZEM 004T and LoRa Schematic
    Devices in this design are connected by soldering Plumbum and electric wire.
    [unodongdiendienap.SchDoc]
2021-01-22 Arduino Uno, DHT11, LoRa SX1278
    Devices in this schematic are soldered by Plumbum and electric wire.
    [unonhietdodoam.SchDoc]
2021-01-22 ATmega328P, DHT11, LoRa SX1278
    [PCB1.PcbDoc, PCB2.PcbDoc, PCB_Project1.PrjPCB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]
2021-01-22 PZEM 004T Module Schematic
    [v9881dmach.SchDoc]
